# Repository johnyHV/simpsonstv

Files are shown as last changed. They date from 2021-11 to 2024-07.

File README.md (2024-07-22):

The original project was created by the user buba447. Manual is [here](https://withrow.io/simpsons-tv-build-guide) and source is [here](https://github.com/buba447/simpsonstv). Original 3D model is [here](https://www.thingiverse.com/thing:4943159)

Second user created new 3D model for 4" Waveshare HDMI display. Original 3D model is [here](https://www.thingiverse.com/thing:5019648)

Presentation video is [here](https://www.youtube.com/watch?v=3tjLVFxXQzM)

---
# Manual Content
1. [ My changes ](#my_changes)
2. [ 3D model ](#3d_model)
3. [ HW parts ](#hw_parts)
4. [ HW construction ](#hw_construction)
5. [ Instalation ](#instalation)
6. [ Image ](#images_url)
7. [ How to use ](#howtouse)

---

# My changes

My changes, all tested on the RPI ZERO:
- added pause video, when is button not pulled.
- added mute audio amplifier if is button not pulled
- minor improvements to 3D models
- added button to 3D model VCR
- used different speaker
- design improvement. is more solid
- added space for USB port in the 3D model, and script for autocopy movie from USB mass storage devices to RPI 
- added feature "next movie" for right button on the VCR
- added feature rewid 15second back for the left button on the VCR
- added usb A connector for autocopy movie from USB flash drive to micro SD card
- new scriprt and service for autocopy movie from USB stick to micro SD card
- added second player script player-playlist.py. This script saving last played video, and after reboot can continue playing last video 

# TODO
- add continue playing the last movie

---

# 3D model

My 3D model is stored on the [Printables](https://www.prusaprinters.org/prints/90361-simpsons-tv) page

---

# HW parts

- 1k potentiometer [here](https://www.tme.eu/en/details/pc16bu-1k-lin/cond-plastic-single-turn-potentiometers/omeg/)
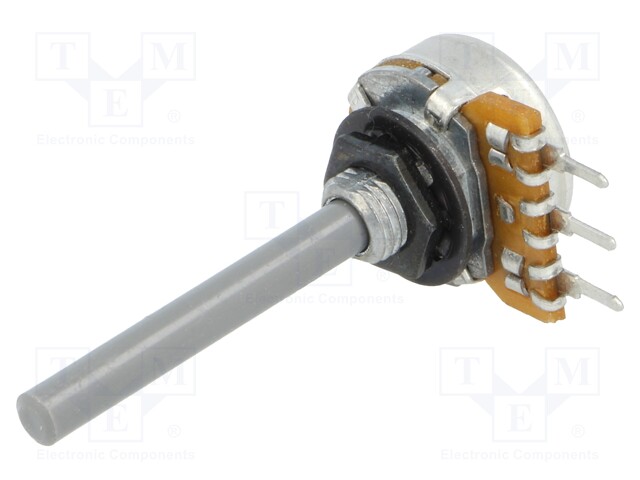
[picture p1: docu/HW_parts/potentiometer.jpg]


- 7x7mm switch [here](https://www.aliexpress.com/item/32704922363.html)
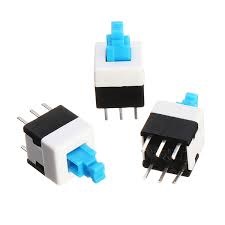
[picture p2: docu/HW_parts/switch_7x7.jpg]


- 4" HDMI Waveshare LCD 800x400 [here](https://rlx.sk/sk/9-5-lcd-display/5454-4inch-hdmi-lcd-800480-ips-waveshare-4-touch-screen-lcd-hdmi-interface-ips-screen-designed-for-raspberry-pi-12030.html)
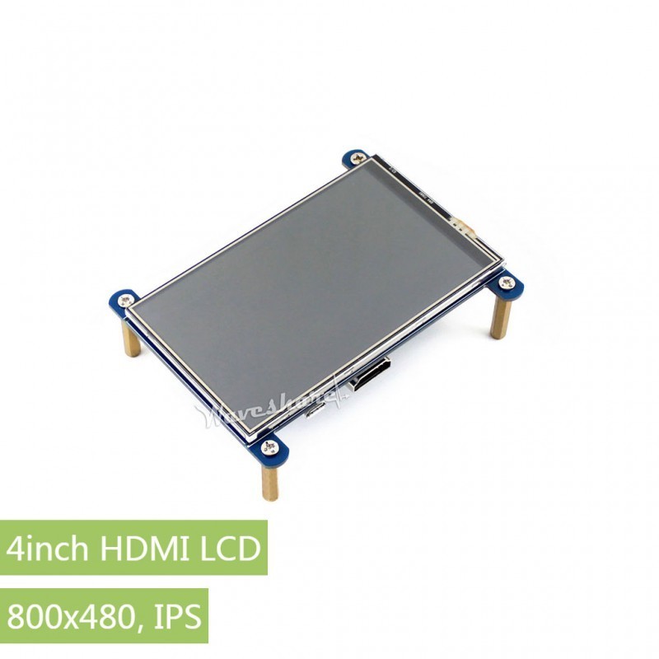
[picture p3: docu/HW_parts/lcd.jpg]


- HDMI connector DIY [here](https://rpishop.cz/redukce/2176-waveshare-mini-hdmi-adapter-pro-diy-hdmi-kabel.html)
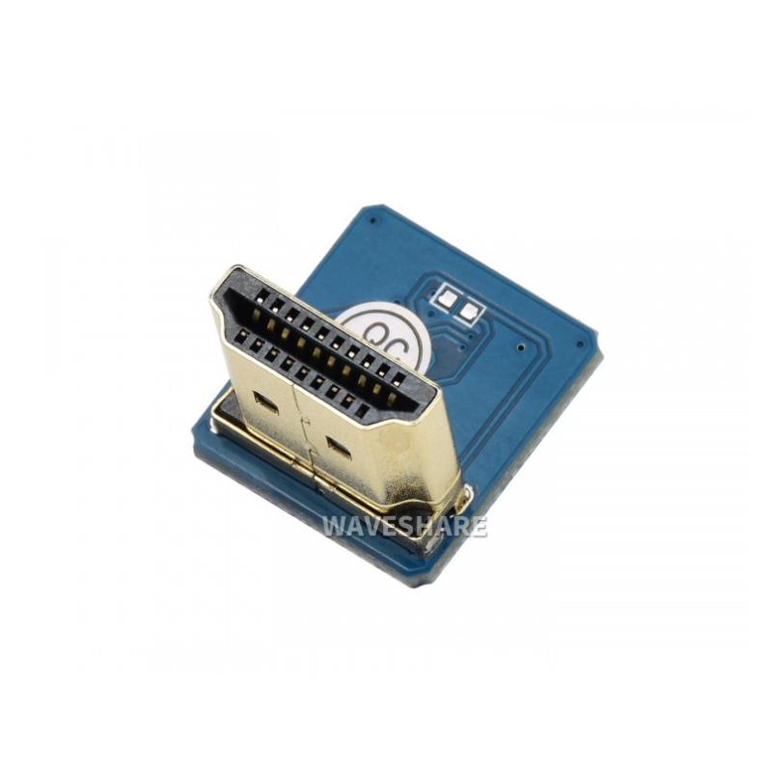
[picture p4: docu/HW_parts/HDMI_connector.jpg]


- MINI HDMI connector DIY [here](https://rpishop.cz/redukce/1205-waveshare-hdmi-adapter-pro-diy-hdmi-kabel-pravouhy.html)
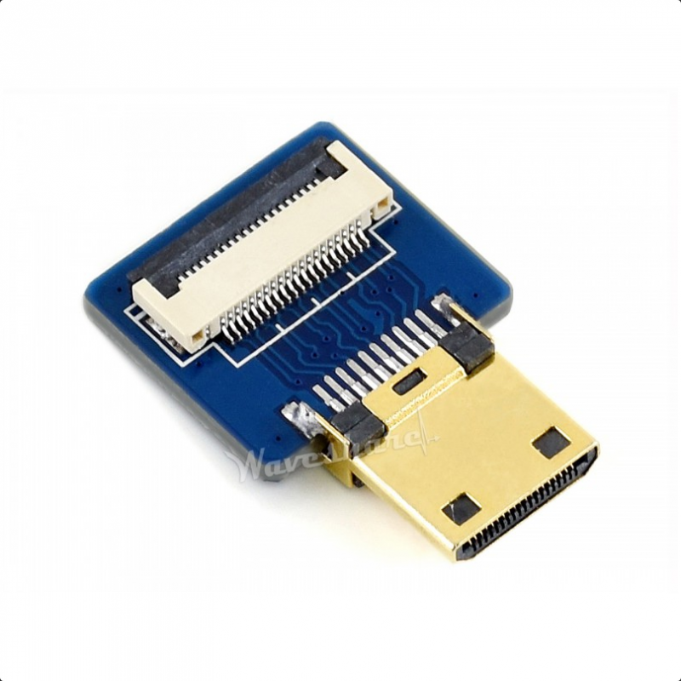
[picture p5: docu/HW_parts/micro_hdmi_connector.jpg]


- HDMI cable DIY [here](https://rpishop.cz/hdmi/1209-waveshare-diy-hdmi-plochy-kabel-02m.html)
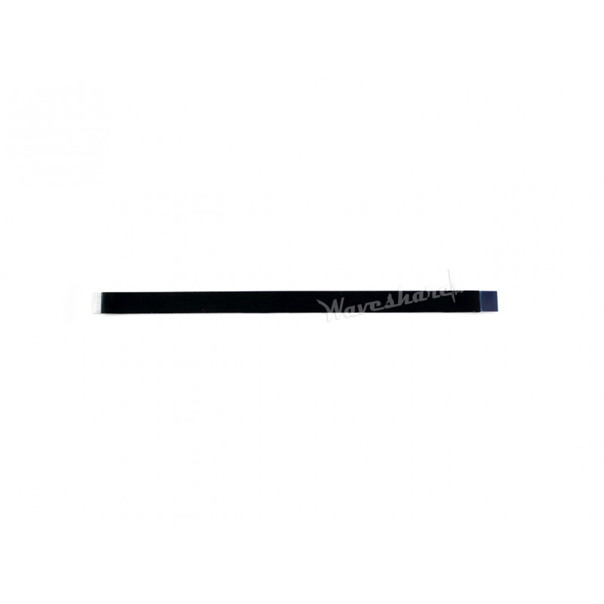
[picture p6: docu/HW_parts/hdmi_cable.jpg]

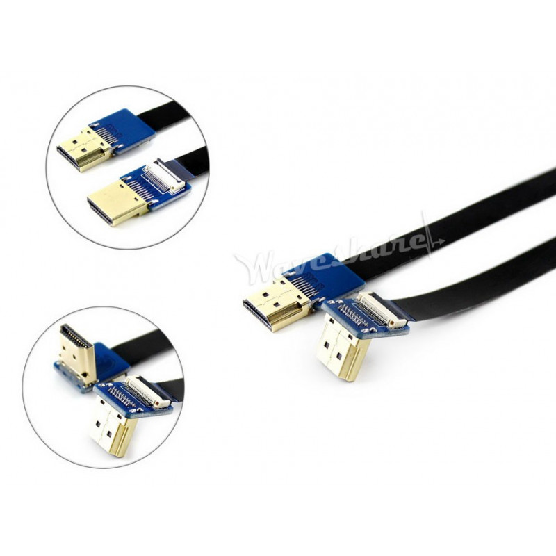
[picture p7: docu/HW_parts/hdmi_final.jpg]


- speaker [here](https://rpishop.cz/reproduktory/1204-waveshare-8-5w-reproduktor.html)
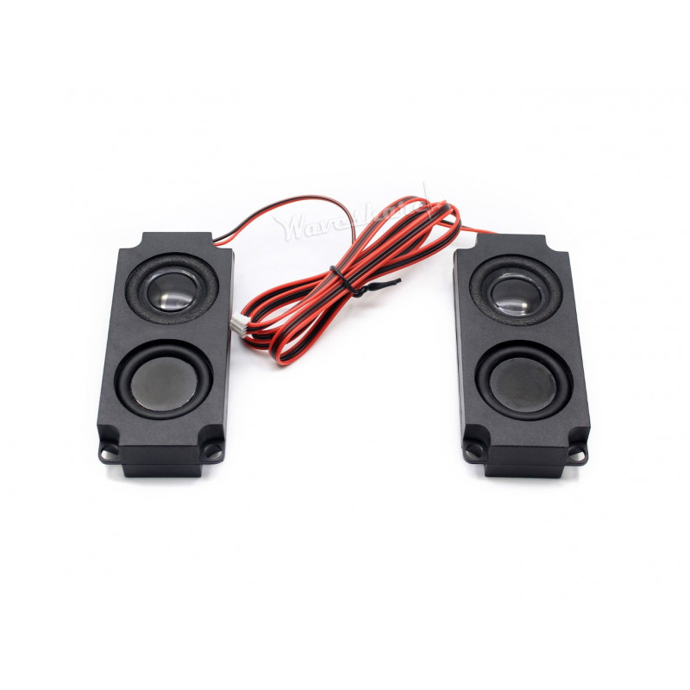
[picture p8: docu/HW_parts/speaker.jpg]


- rpi zero [here](https://rpishop.cz/zero/632-raspberry-pi-zero.html)
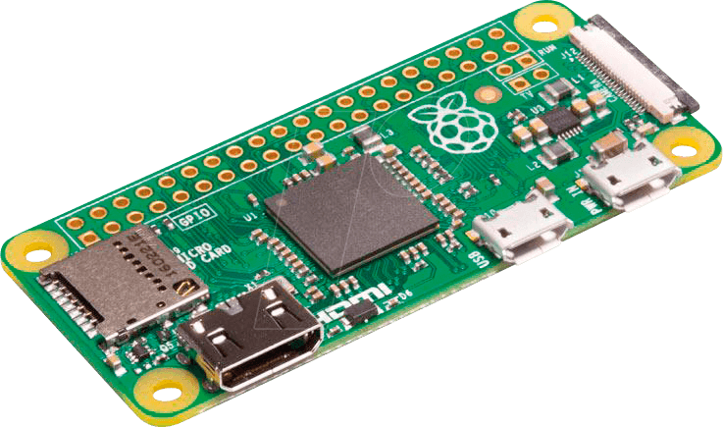
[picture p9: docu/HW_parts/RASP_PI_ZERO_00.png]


- audio amplifier PAM8302 [here](https://rlx.sk/sk/audio-voice-boards-speech-recognition/3397-mono-25w-class-d-audio-amplifier-pam8302-adafruit-2130.html)
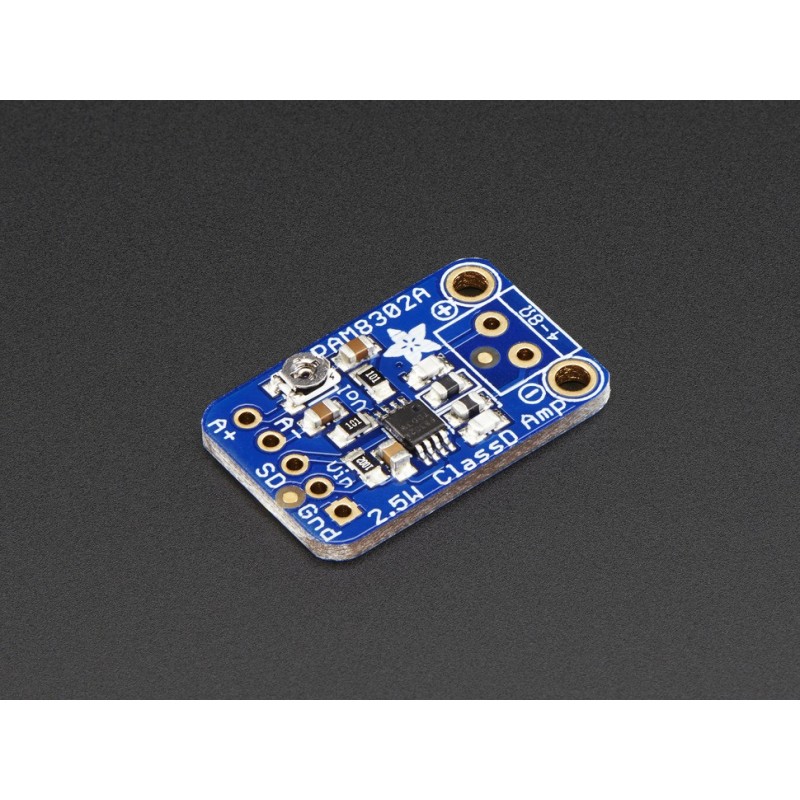
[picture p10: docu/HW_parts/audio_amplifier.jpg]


- capacitor 2.2uF/50V
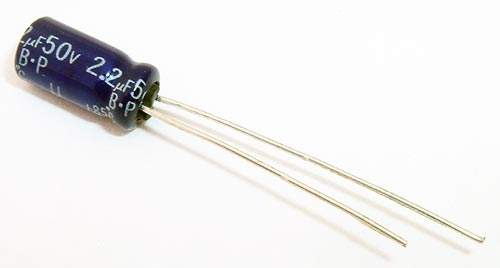
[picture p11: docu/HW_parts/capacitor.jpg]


- screw M3 4x
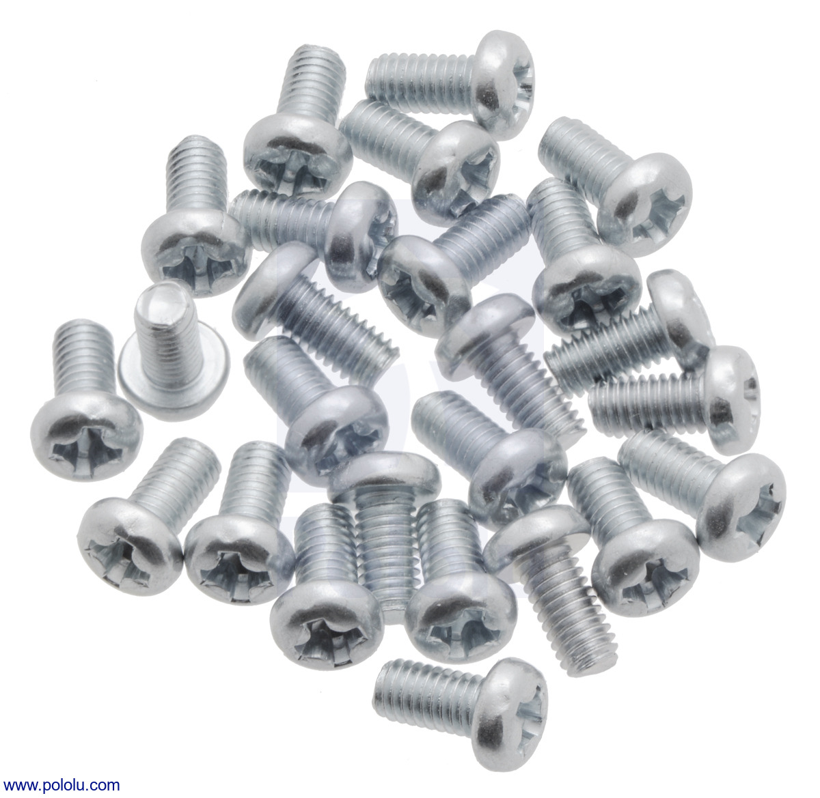
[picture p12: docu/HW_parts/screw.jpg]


- switch 6x6mm 2x [here](https://www.tme.eu/en/details/tact-64k/microswitches-tact/ninigi/) **watch out for the length of the button**
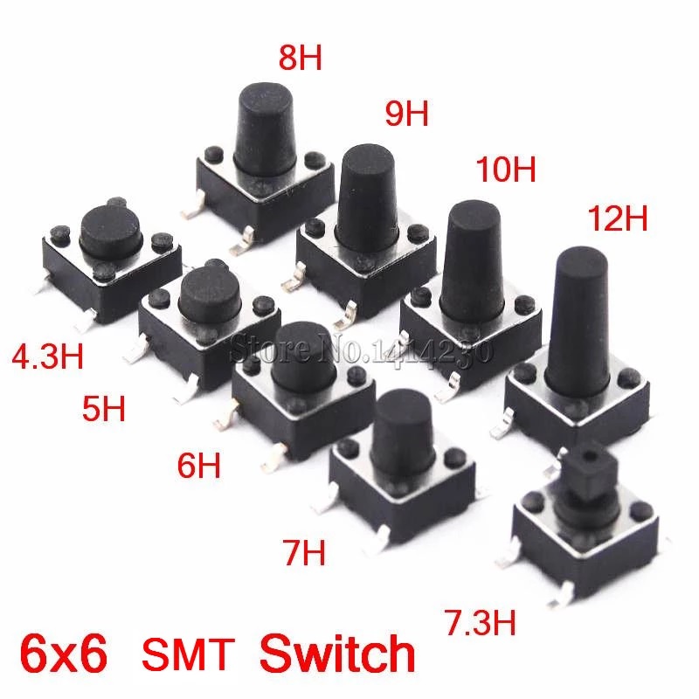
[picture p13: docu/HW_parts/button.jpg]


- micro USB connector [here](https://www.aliexpress.com/item/32916571891.html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)
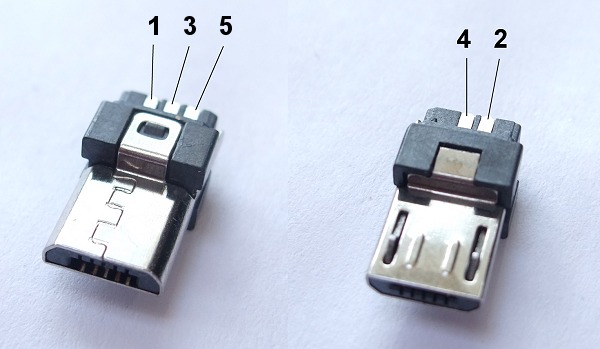
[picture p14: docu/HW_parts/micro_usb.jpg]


- PCB with micro USB connector [here](https://www.aliexpress.com/item/4000484202812.html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)
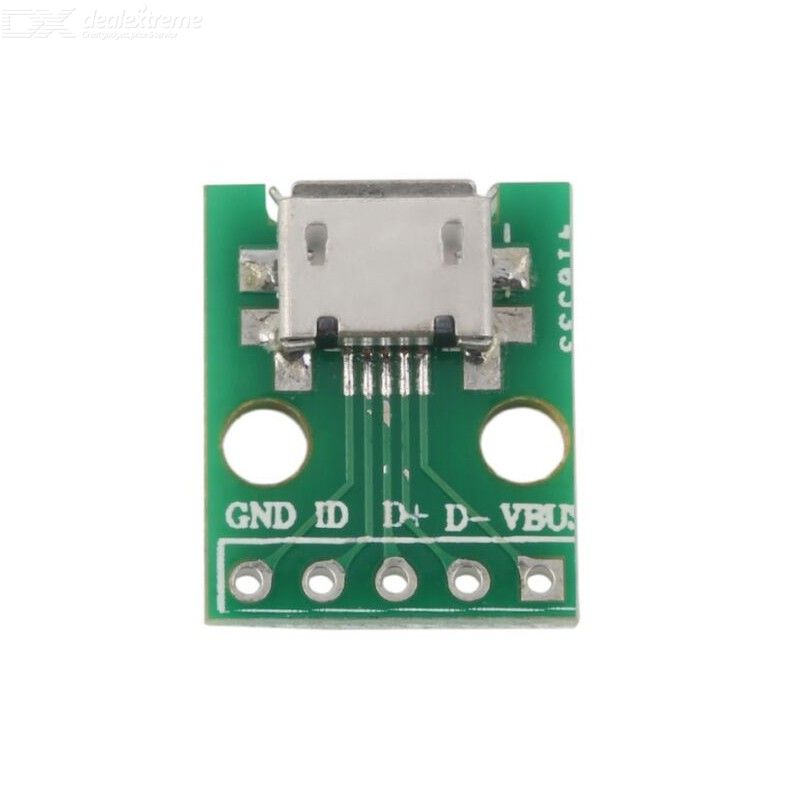
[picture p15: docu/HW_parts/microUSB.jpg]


- magnet circle 6x2mm
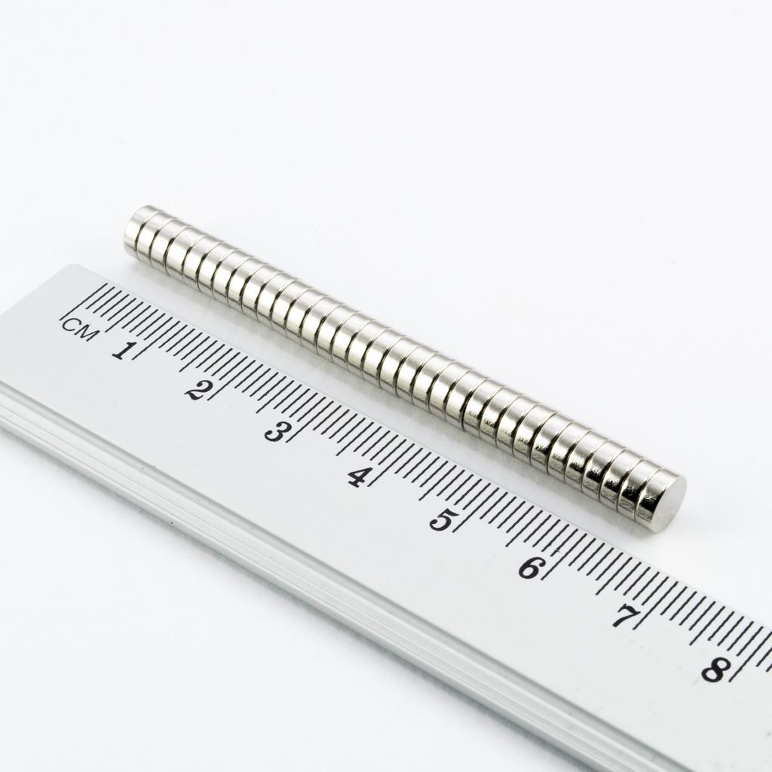
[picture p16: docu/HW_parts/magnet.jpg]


- 3mm LED
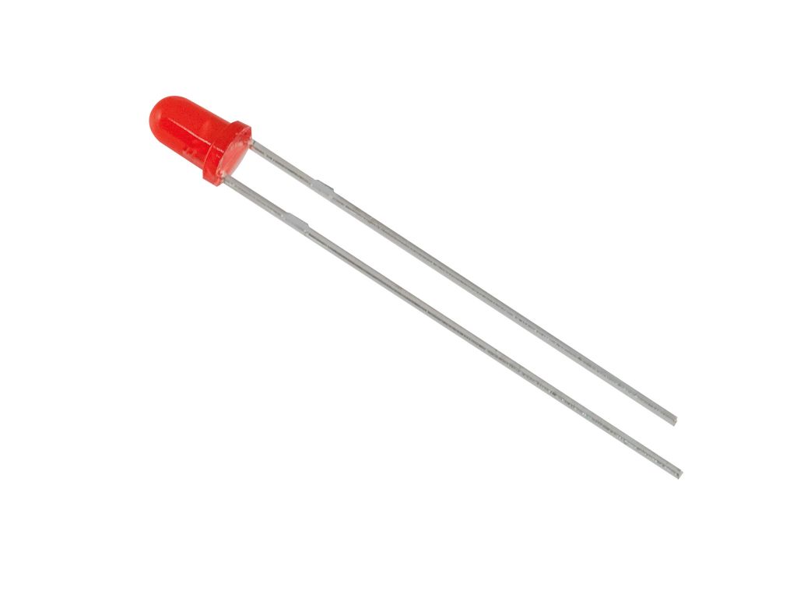
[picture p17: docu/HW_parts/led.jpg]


- USB A connector [here](https://www.aliexpress.com/item/4000806581109.html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)
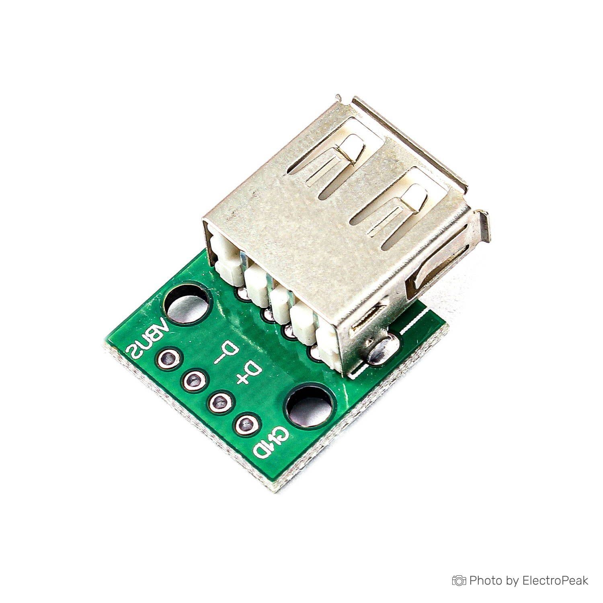
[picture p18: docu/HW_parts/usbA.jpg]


- Wires
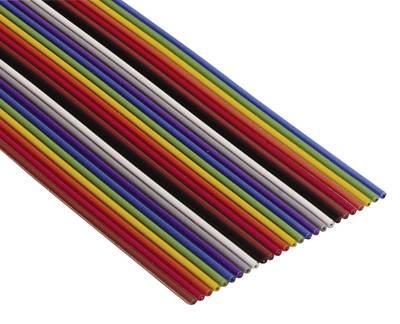
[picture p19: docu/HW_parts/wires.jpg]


- long pin header 25mm, male, 2.54MM PITCH [here](https://www.aliexpress.com/item/32851444441.html)
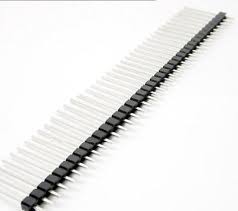
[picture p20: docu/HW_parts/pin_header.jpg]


---

# HW construction

Approximate schematic. Missing USB and LCD parts
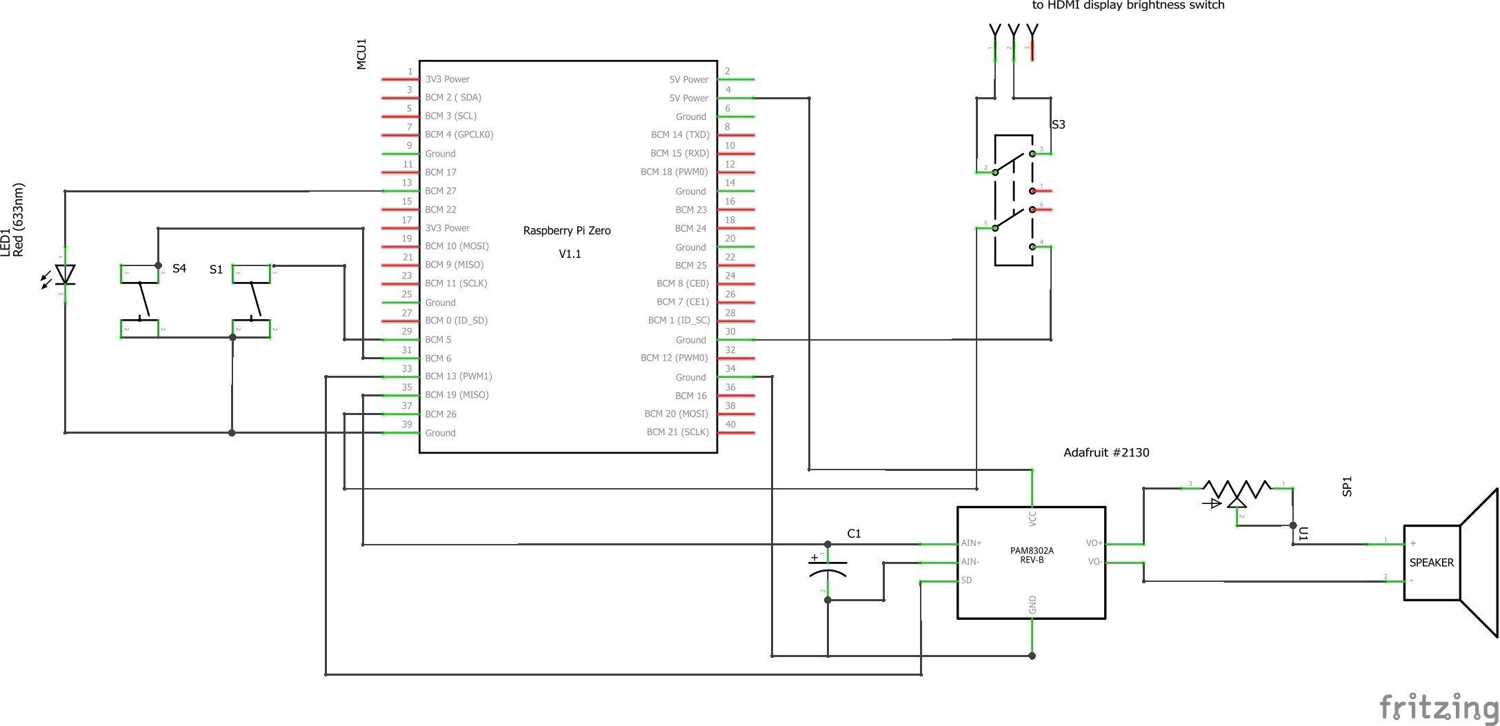
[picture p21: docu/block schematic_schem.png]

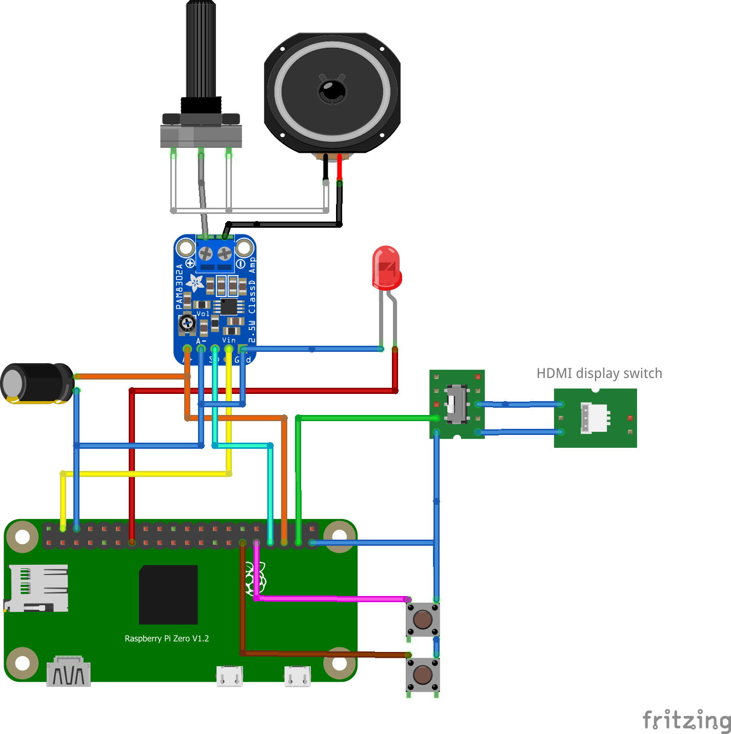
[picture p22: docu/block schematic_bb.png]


## Pinout
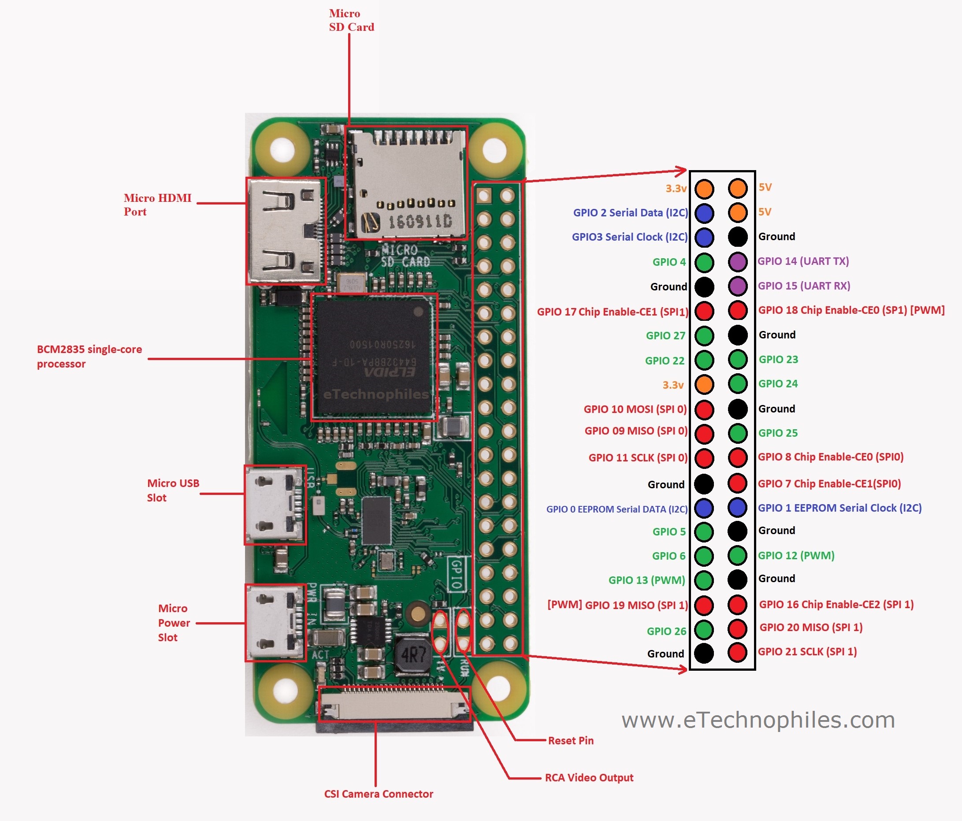
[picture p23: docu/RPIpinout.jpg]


Power switch
```
POWER SWITCH PIN A -> GPIO26
POWER SWITCH PIN B -> GND
```
Audio amplifier
```
AUDIO AMPLIFIER SIGNAL -> GPIO19
AUDIO AMPLIFIER SHUT DOWN -> GPIO13
AUDIO AMPLIFIER POWER -> +5V
AUDIO AMPLIFIER GROUND -> GND
```
Buttons
```
BUTTON NEXT VIDEO PIN A -> GPIO6
BUTTON NEXT VIDEO PIN B -> GND

BUTTON XXX PIN A -> GPIO5
BUTTON XXX PIN B -> GND
```
LED
```
LED FOR INDICATE USB COMMUNICATION ANODE -> GPIO27
LED FOR INDICATE USB COMMUNICATION CATODE -> GND
```

# Soldering and connecting components
1. Connect switch to LCD display (for enable/disable blacklight). Switch the switch on the LCD to the off position 
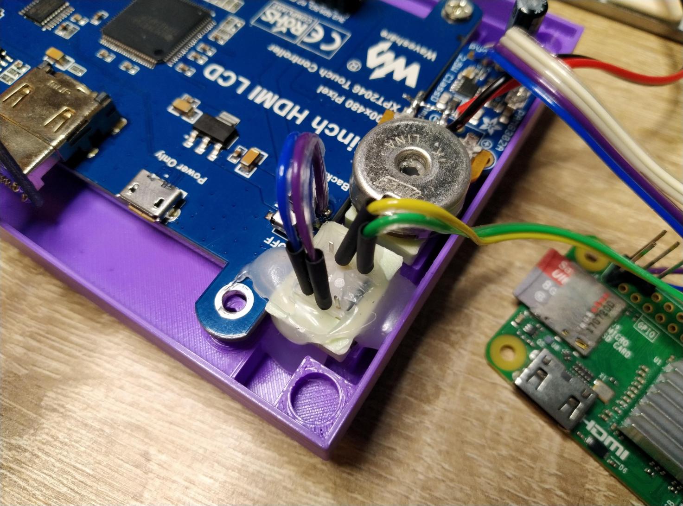
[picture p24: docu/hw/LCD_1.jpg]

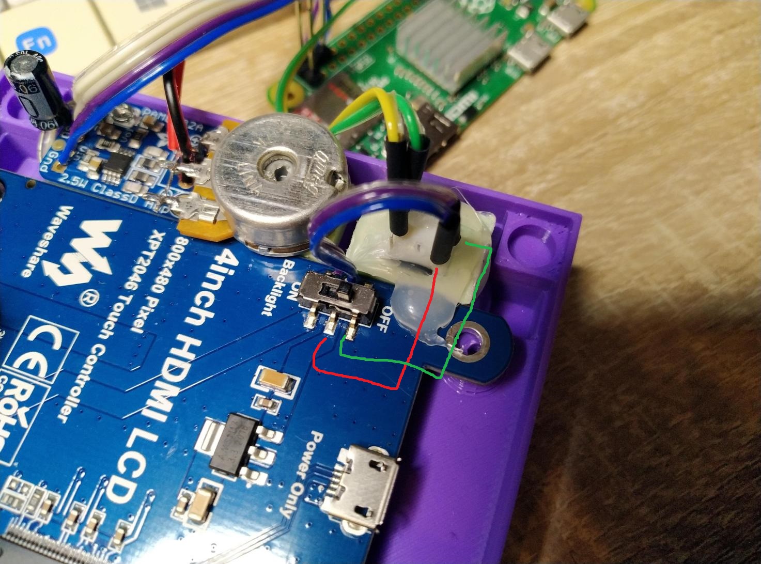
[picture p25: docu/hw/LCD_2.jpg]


2. Connect switch to RPI. for RPI pause information
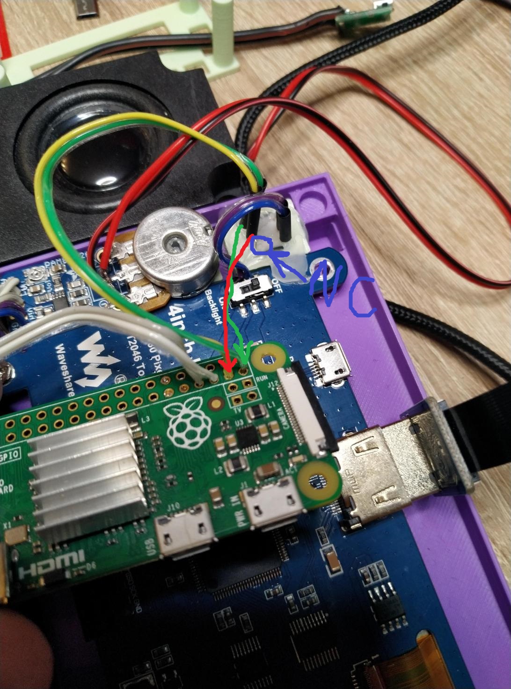
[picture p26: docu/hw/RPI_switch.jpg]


```
- one switch pole to GPIO26
- second pole to GND
```

3. Solder 4pcs long pin header male to RPI board, to connect power to LCD from RPI. long connectors are used for better air circulation, and cooling RPI. You can use heatsink for better cooling
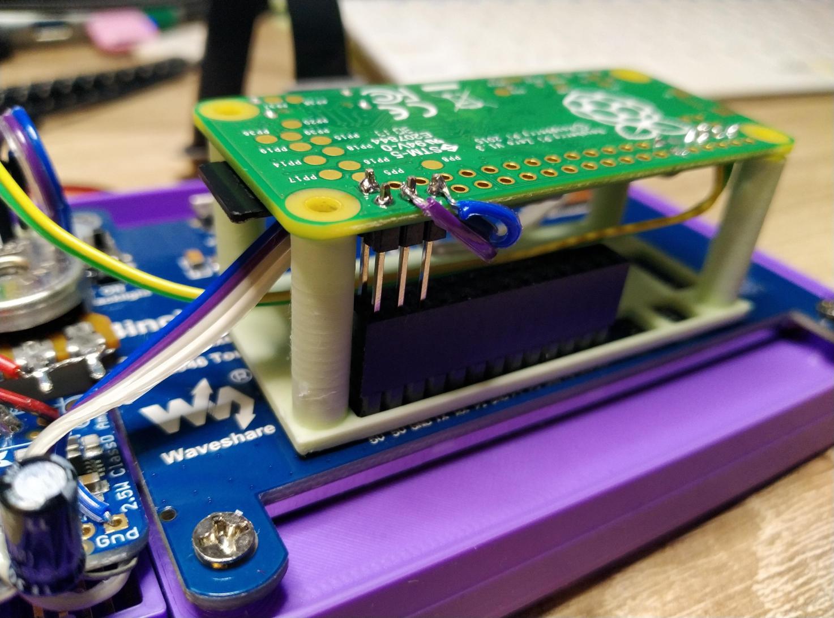
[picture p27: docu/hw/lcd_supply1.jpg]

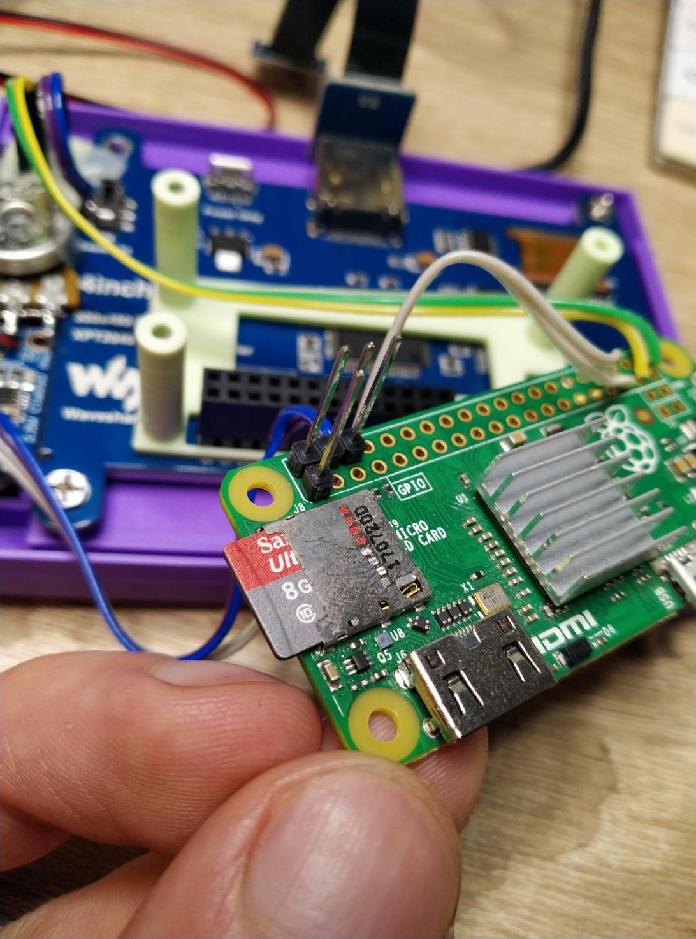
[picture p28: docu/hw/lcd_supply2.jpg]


4. Connect speaker to potentiometer and audio amplifier.
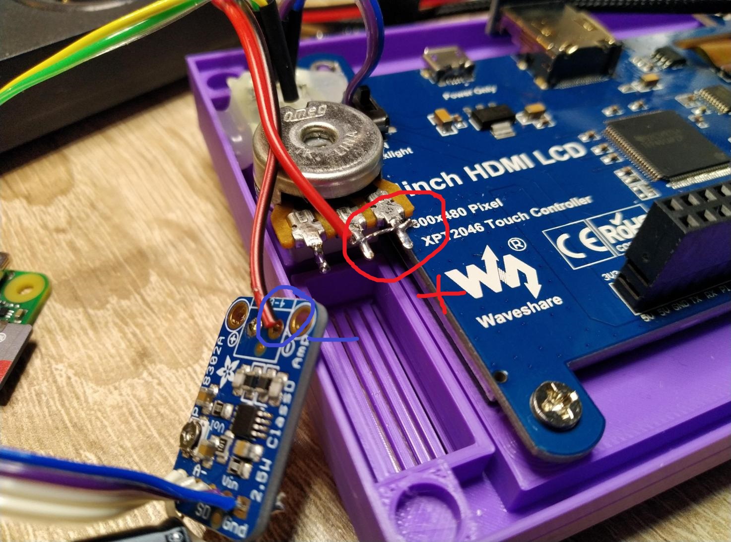
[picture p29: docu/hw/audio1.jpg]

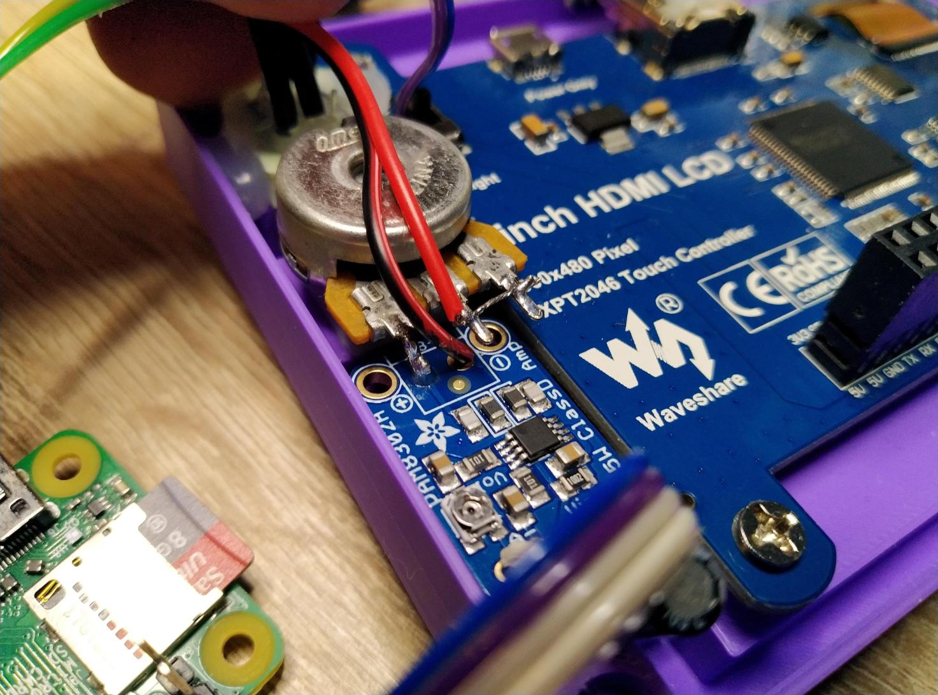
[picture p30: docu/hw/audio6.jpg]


5. Connect audio amplifier to RPI
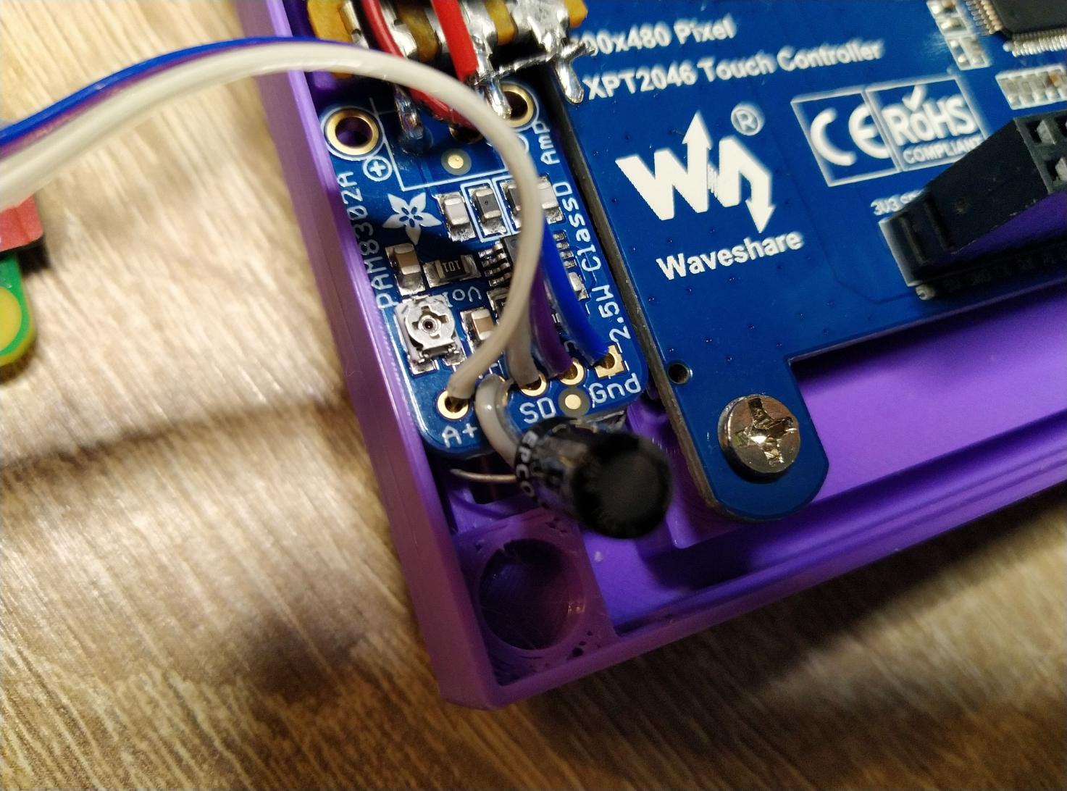
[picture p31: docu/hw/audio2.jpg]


```
- A+ -> audio input -> RPI pin GPIO19
- A- -> audio GND -> RPI pin GND
- SD -> shut down -> RPI pin GPIO13
- Vin -> voltage input -> RPI pin +5V
- Gnd -> ground -> RPI pin GND
```

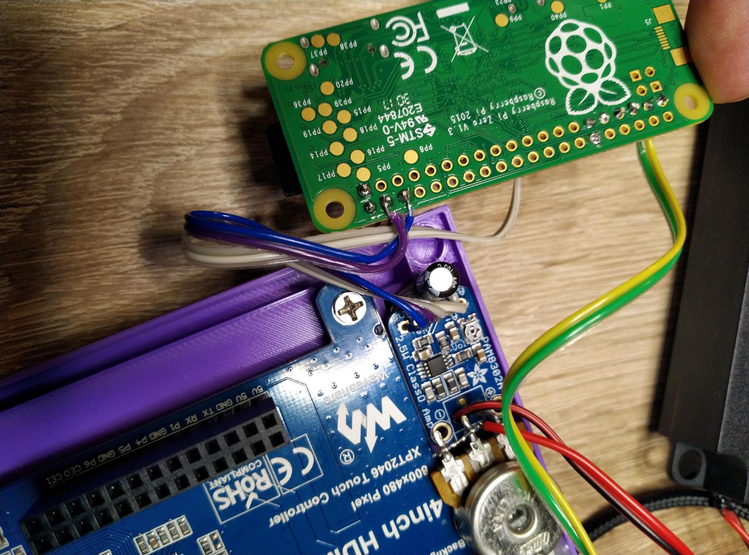
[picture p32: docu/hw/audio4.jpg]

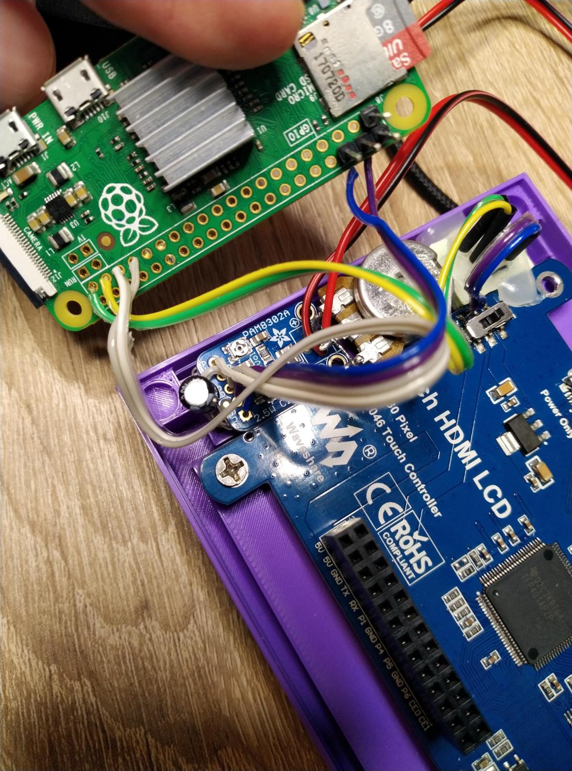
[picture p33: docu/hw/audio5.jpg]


6. Connect 2.2uF capacitor during A+ and GND pin, for a clearer sound
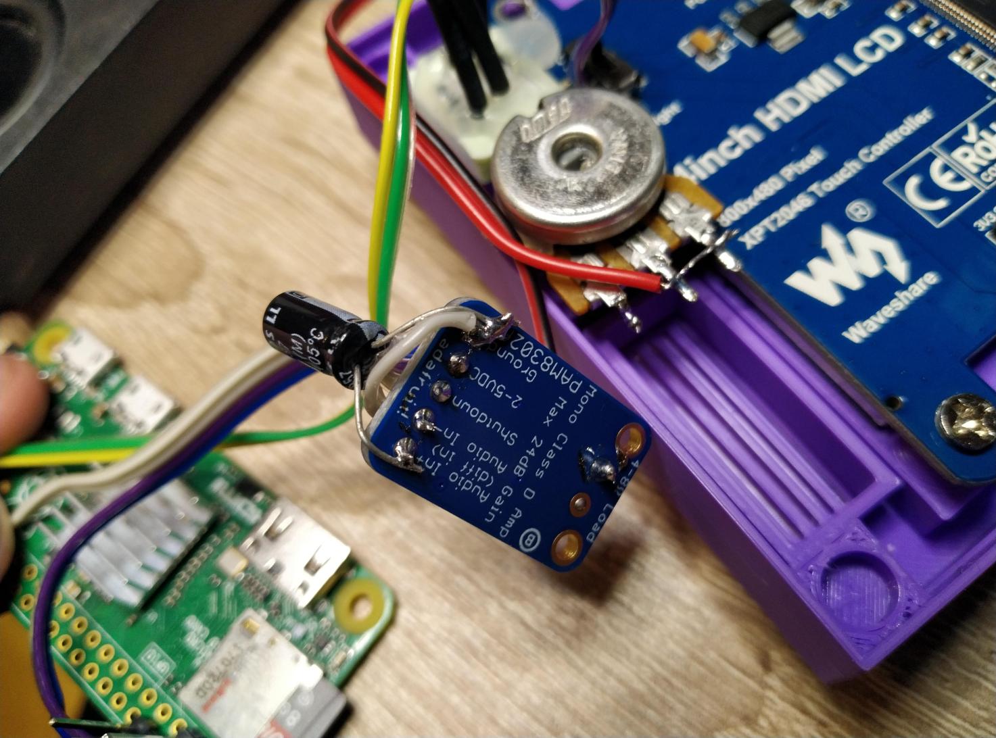
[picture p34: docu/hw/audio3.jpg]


7. Connect HDMI cable
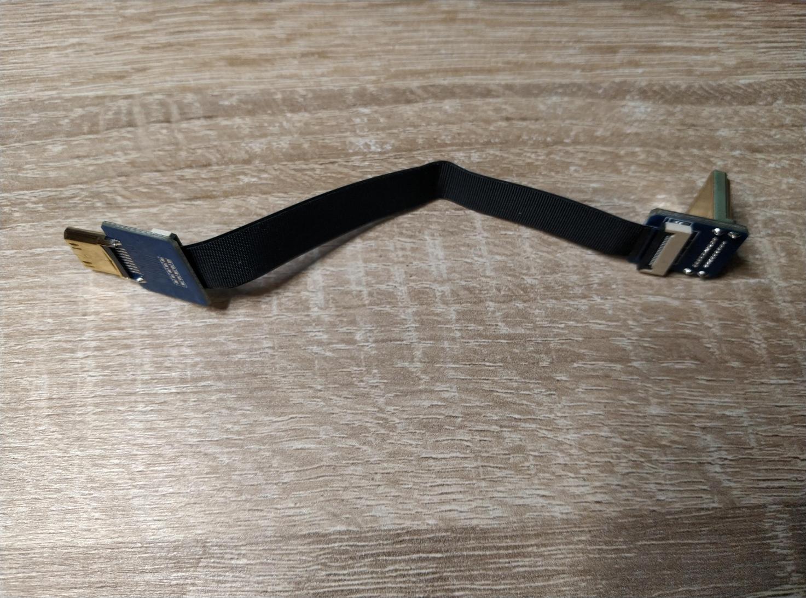
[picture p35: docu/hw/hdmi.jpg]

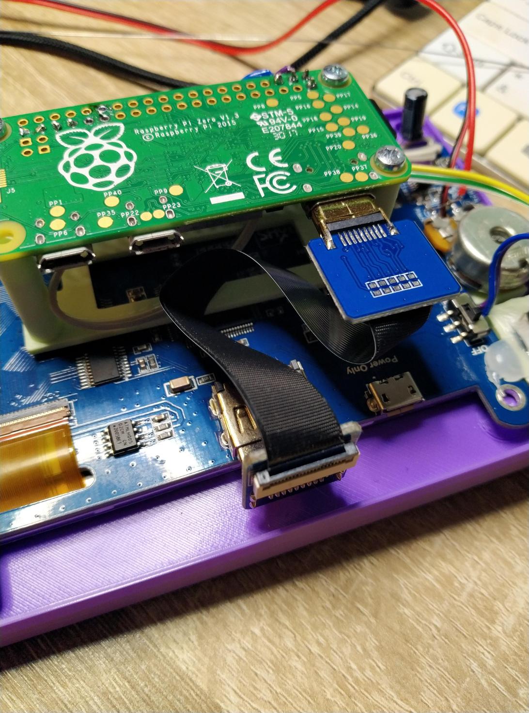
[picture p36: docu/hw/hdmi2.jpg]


8.current view of HW

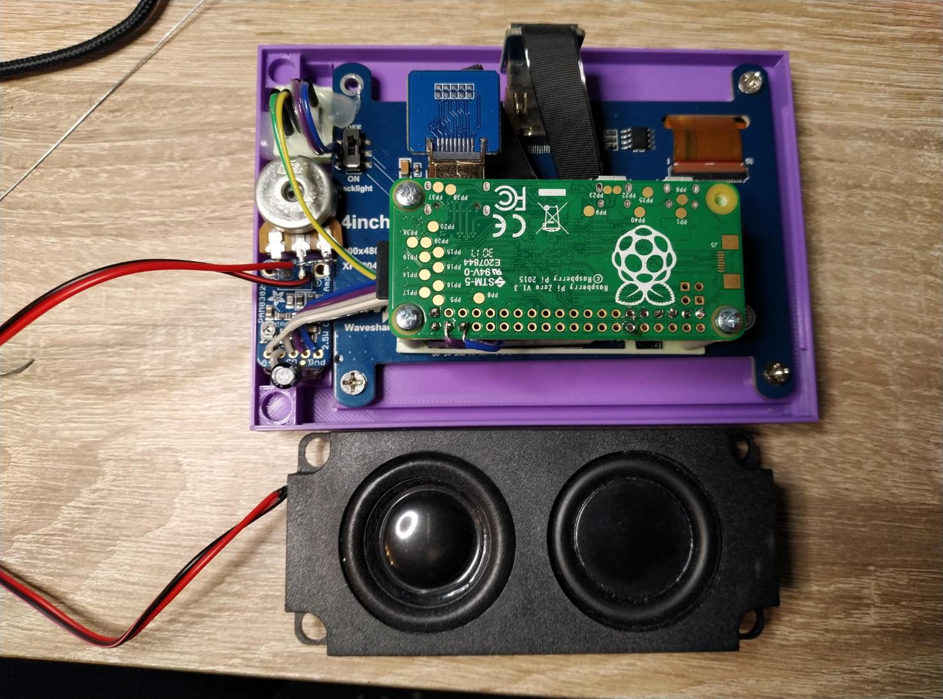
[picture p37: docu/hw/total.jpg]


9. Micro USB connector female
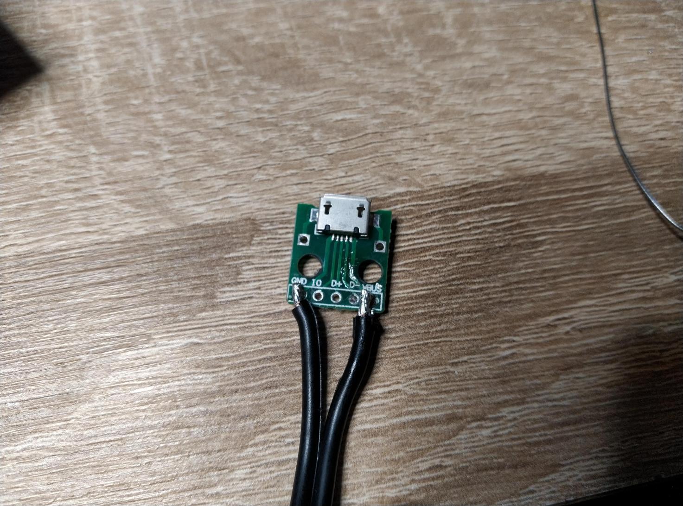
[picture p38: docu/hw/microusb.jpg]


9. Micro USB connector male

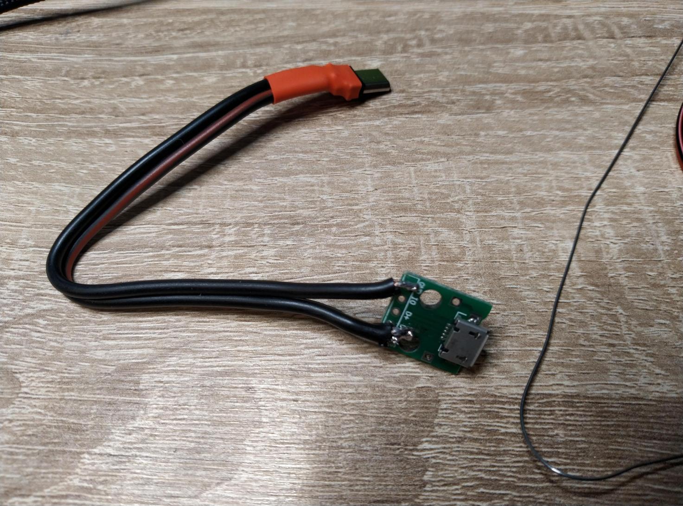
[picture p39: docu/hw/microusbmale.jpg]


10. Button in VCR recorder. We need only 3 wire. One wire is common (GND). Second wire is for next movie, and next wire is for XXX function. solder and glue
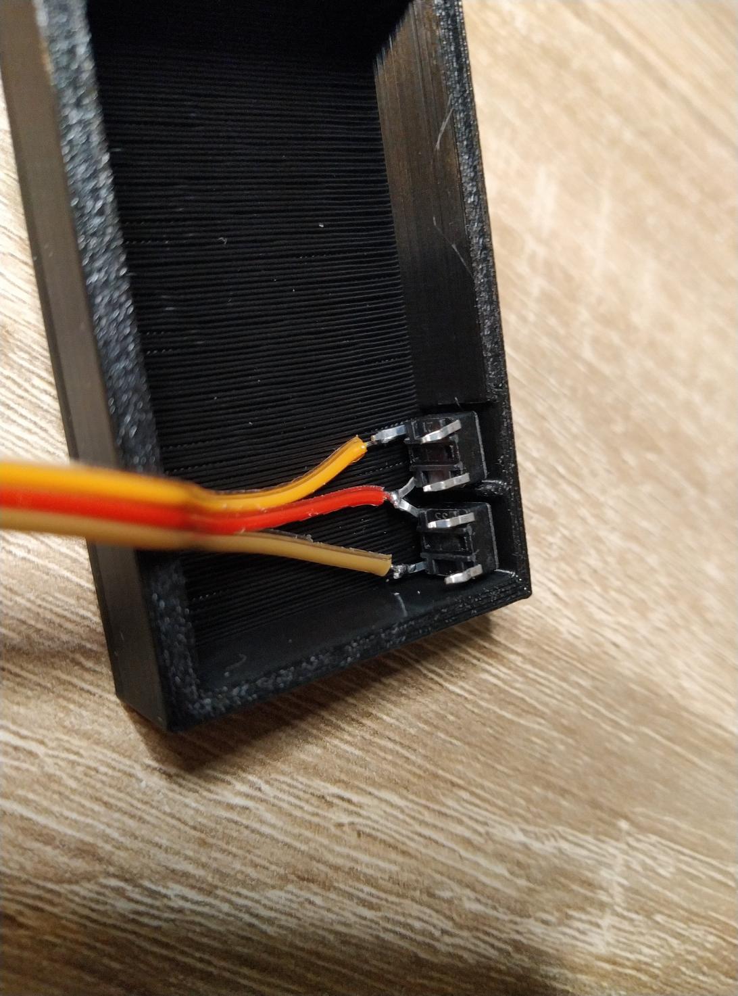
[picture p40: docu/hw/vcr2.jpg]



11. Soldering USB A connector for USB masstorage devices. We need an old micro USB cable or micro USB connector and solder 4 wires. VCC, DATA+, DATA-, GND



12. Soldering LED for indication of copying files from USB stick to microSD card. 



13. And soldering LED to RPI PCB. When maximum output voltage from GPIO is 3.3V and maximum current is 16mA, then we don't need resistor for current limitation. But you can use it if you want

```
LED Anode -> GPIO27
LED Catode -> GND
```



14. Stick the VCR to the top of the box with the super glue


15. Stick the speaker holder to the box with the super glue


16. Stick the PCB with micro USB connector to the box with the glue


17. Stick the PCB with micro A connector to the box with the glue


18. Stick the speaker to the box with the glue


19. Now we can soldering wire from VCR to RPI PCB

```
Wire from button for next movie -> GPIO6
Common wire -> GND
Wire from button for XXX -> GPIO5
```




20. Stick the LED to the box with the glue


21. Stick the magnet to the box with the glue


22. Connect micro USB connector with power supply to RPI


23. Connect micro USB connector for USB stick to RPI


24. Final pictures




---

# Instalation

1. Install OS to micro SD card. For install OS please use Raspberry PI installer [here](https://www.raspberrypi.com/software/)
2. Create a file before inserting the micro SD card **wpa_supplicant.conf** in **boot** partition and add to file
```
country=US
ctrl_interface=DIR=/var/run/wpa_supplicant GROUP=netdev
update_config=1

network={
    ssid="NETWORK NAME"
    psk="NETWORK PASSWORD"
}
```
3. Create a empty file **ssh** before inserting the micro SD card in **boot** partition. For enable SSH server after booting linux
4. Now you can insert microSD card to RPI and power on. After booting is raspberry-pi automatically connected to WI-FI, with SSH server. After booting you can see IP at the home screen


Now we can use 2 method for instalation and configuration OS. First method is continue to steps 5 and more.

Second method is use scripts for install all neccesary package and configuring OS. This method skip steps 5 -> 18. Method is not fully tested, is only experimental.
```
sudo apt-get install git
cd ~
git clone https://github.com/johnyHV/simpsonstv
cd simpsonstv
sudo ./install_01.sh
```

After reboot RPI
```
cd simpsonstv
sudo ./ install_02.sh
```
If you use this method, then after previous commands please continue to [ step 19 ](#step_19).

5. **Update OS**
```
sudo apt-get update
sudo apt-get upgrade
sudo rpi-update
sudo apt-get upgrade
sudo reboot
```

6. **LCD driver**. go to **/boot/config.txt** and add next lines for enable LCD drivers. Save, and reboot RPI. Manual for installation  manual is [here](https://www.waveshare.com/wiki/4inch_HDMI_LCD)

```
sudo nano /boot/config.txt
```

add to end file

```
hdmi_group=2
hdmi_mode=87
hdmi_timings=480 0 40 10 80 800 0 13 3 32 0 0 0 60 0 32000000 3
dtoverlay=ads7846,cs=1,penirq=25,penirq_pull=2,speed=50000,keep_vref_on=0,swapxy=0,pmax=255,xohms=150,xmin=200,xmax=3900,ymin=200,ymax=3900
display_rotate=3
hdmi_drive=1
hdmi_force_hotplug=1
```

7. **LCD driver.** Install drivers for LCD
```
git clone https://github.com/waveshare/LCD-show.git
cd LCD-show/
chmod +x LCD4-800x480-show
sudo ./LCD4-800x480-show
```
8. **Enable audio.** add to file **/boot/config.txt**
```
sudo nano /boot/config.txt
```
add to end file
```
dtparam=audio=on
dtoverlay=audremap,enable_jack,pins_18_19
```
9. **Enable audio.** Update file **/etc/rc.local**
```
sudo nano /etc/rc.local
```
add to end file, before **exit 0** line
```
raspi-gpio set 18 op dl
raspi-gpio set 19 op a5 
raspi-gpio set 8 a2
raspi-gpio set 7 a2
```
10. Update **/boot/cmdline.txt**
```
sudo nano /boot/cmdline.txt
```
my file contain
```
console=serial0,115200 console=tty1 root=/dev/mmcblk0p2 rootfstype=ext4 elevator=deadline fsck.repair=yes rootwait quiet splash fbcon=map:10 fbcon=font:ProFont6x11
```
11. **Install package to OS**
```
sudo apt-get install omxplayer git mc screen rsync
```
12. **Clone repository**
```
cd ~
git clone https://github.com/johnyHV/simpsonstv
cd simpsonstv
```
13. **Service**. Service for management buttons
```
sudo cp simpsonstv/services/tvbutton.service /etc/systemd/system/tvbutton.service
```
14. **Service**. Service for management video player
```
sudo cp simpsonstv/services/tvplayer.service /etc/systemd/system/tvplayer.service
```
15. **Update permission for script**
```
sudo chmod +x /home/pi/simpsonstv/dbuscontrol.sh
```
16. **Version with USB**. Service for auto copy files from USB mass storage devices to RPI flash drive. 
```
sudo cp simpsonstv/services/tvautocopy.service /etc/systemd/system/tvautocopy.service
```
17. **Version with USB**. Enable autocopy service
```
sudo chmod +x /home/pi/simpsonstv/autocopy.sh
```
18. **Service**. Enable services
```
sudo systemctl enable tvbutton.service
sudo systemctl enable tvplayer.service
sudo systemctl enable tvautocopy.service
```

19. **Reboot system**
```
sudo reboot
```
20. Now we need convert video file to **mp4** format. For this exist python script encode.py stored in **~/simpsonstv/video/**. Video file you can convert on RPI (but it's very tedious and slow) or on the your computer. You can use different SW for converting video file. 
```
~/simpsonstv/video/
sudo python encode.py
```
21. **Copy video to RPI**. 
**Copy via network** For example, you can use **scp** or **winscp**, for copy files via network sfp to RPI. Directory for video
```
~/simpsonstv/videos
```
**Copy movie from USB**. We need create a folder **simpsonstv** on the USB key in root, and store movies to this folder. After booting linux, and insert USB key is automaticly started script for copy movies from FLASH drive to micro SD card. the LED near the USB port lights up during the copying process. When copying is complete, the LED will turn off and you can disconnect the USB key



22. **Two player scripts** There are currently two existing scripts for two-player functionality. The first script, player.py, is standard and plays random videos. The second script, player-playlist.py, saves the last played video, allowing the device to continue from where it left off after a reboot. If opting for the second script, it's necessary to rename the script
```
cd simpsonstv
mv player.py player-random.py
mv player-playlist.py player.py
sudo systemctl restart tvplayer.service
```
---

# Image
We can download my RPI ZERO image from my [gdrive](https://drive.google.com/drive/folders/1mnJnrXVBaZO_8UrxD8tn1eNyA690npIP?usp=sharing). I don't tested if is this image compatible with ZERO W or ZERO 2 W

- OS: raspberry-pi OS 32bit
- username: pi
- password: raspberry

---

# How to use

***TODO***

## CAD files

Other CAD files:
fusion/VCR.f3d
fusion/potentiometer_holder.f3d
fusion/potentiometer_knob.f3d
fusion/rpi_holder.f3d
fusion/speaker_holder.f3d
fusion/switch_holder.f3d
fusion/switch_knob.f3d

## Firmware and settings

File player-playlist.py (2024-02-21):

import os
import random
import time
from subprocess import PIPE, Popen, STDOUT

directory = os.path.join(os.path.dirname(os.path.realpath(__file__)), 'videos')
last_played_file_name = "LastPlayed.txt"

def getVideos():
    videos = [os.path.join(directory, file) for file in sorted(os.listdir(directory)) if file.lower().endswith('.mp4')]
    return videos

def saveLastPlayed(video):
    with open(last_played_file_name, 'w') as file:
        file.write(video)

def getLastPlayed():
    if not os.path.exists(last_played_file_name):
        return ''
    with open(last_played_file_name, 'r') as file:
        return file.read()

def playVideos():
    videos = getVideos()
    if not videos:
        print('No videos found')
        time.sleep(5)
        return
    last_played = getLastPlayed()
    start_index = 0
    if last_played in videos:
        start_index = videos.index(last_played)
    for video in videos[start_index:]:
        saveLastPlayed(video)
        print("Current video: " + video)
        playProcess = Popen(['omxplayer', '--no-osd', '--win', '00,00,750,480', video])
        playProcess.wait()

while (True):
    playVideos()

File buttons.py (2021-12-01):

import RPi.GPIO as GPIO
import time
import os
import subprocess

os.system('raspi-gpio set 19 ip')
GPIO.setmode(GPIO.BCM)
GPIO.setup(26, GPIO.IN, pull_up_down=GPIO.PUD_UP) # button
GPIO.setup(18, GPIO.OUT)  # screen (not use with waveshare display)
GPIO.setup(13, GPIO.OUT)  # audio amplifier
GPIO.setup(6, GPIO.IN, pull_up_down=GPIO.PUD_UP) # button next video
GPIO.setup(5, GPIO.IN, pull_up_down=GPIO.PUD_UP) # power off


def turnOnScreen():
    os.system('raspi-gpio set 19 op a5')
    GPIO.output(18, GPIO.HIGH)
    os.system('/home/pi/simpsonstv/dbuscontrol.sh pause') # pause video
    GPIO.output(13, GPIO.HIGH) # unmute audio amplifier

def turnOffScreen():
    os.system('raspi-gpio set 19 ip')
    GPIO.output(18, GPIO.LOW)
    os.system('/home/pi/simpsonstv/dbuscontrol.sh pause') # play video
    GPIO.output(13, GPIO.LOW) # mute audio amplifier

def playNextVideo():
    print ("Next movie")
    os.system('ps -aux | grep omxplayer | grep -v grep | awk \'{ print $2 }\' | xargs kill -9')

def rewidVideo():
    print ("rewid 15 second")
    position = int(os.popen("/home/pi/simpsonstv/dbuscontrol.sh status | grep 'Position:' | awk '{print $2}'").read())
    print (position)
    rewidTime = int(15) # 15 second
    newPosition = position - (rewidTime * 1000 * 1000) # position - 15 second (time must be in microsecond)
    print (newPosition)
    os.system('/home/pi/simpsonstv/dbuscontrol.sh setposition %s' % (newPosition)) #

def shutdownSystem():
    print ("Poweroff")
    os.system('poweroff')

turnOffScreen()
screen_on = False
buttonRight = True
buttonLeft = True

while (True):
    # If you are having and issue with the button doing the opposite of what you want
    # IE Turns on when it should be off, change this line to:
    # input = not GPIO.input(26)
    time.sleep(0.3)

    input = not GPIO.input(26)
    inputButtonRight = GPIO.input(6)
    inputButtonLeft = GPIO.input(5)

    if input != screen_on:
        screen_on = input
        if screen_on:
            turnOnScreen()
        else:
            turnOffScreen()

    # check push left and right button
    if ((inputButtonLeft != buttonLeft) and (inputButtonRight != buttonRight)):
        inputButtonLeft != buttonLeft
        inputButtonRight != buttonRight
        if (buttonLeft and buttonRight):
            shutdownSystem()

    else:
        # check push right button
        if inputButtonRight != buttonRight:
            buttonRight = inputButtonRight
            if buttonRight:
                playNextVideo()

        # check push left button
        if inputButtonLeft != buttonLeft:
            buttonLeft = inputButtonLeft
            if buttonLeft:
                rewidVideo()

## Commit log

2021-12-01 [sw]
    - update buttons script
2021-12-01 [fusion]
    - add fusion files
    [VCR.f3d, potentiometer_holder.f3d, potentiometer_knob.f3d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]
2021-12-24 [docu]
    - add fritzing schematic
    [block schematic.fzz]
2023-11-09 update documentation
    [block schematic.fzz]
